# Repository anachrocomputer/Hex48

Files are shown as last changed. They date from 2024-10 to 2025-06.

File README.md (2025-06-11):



# Hex48 #

PCB design for a hexagonal prototyping board capable of holding DIL chips with
up to 48 pins.

## The Problem ##

Everybody has prototyping PCBs in rectangular form, but what other shapes tesselate well?
How about hexagons, would they work?
And why stop at 40-pin DIL packages when chips like the 68008 come in 48-pin DIL?

## The Solution ##

This PCB design mounts the DIL part on a hexagonal board that can be easily tesselated.
It has mounting holes for M3 PCB standoffs, or it can be fitted with non-slip feet.
In extreme cases, a heavy base can be made out of an insulator such as slate.

## KiCad ##

This design has been created using the Open Source CAD package KiCad, V8.0.

To install it on Ubuntu Linux:

`sudo add-apt-repository ppa:kicad/kicad-8.0-releases`

`sudo apt update`

`sudo apt install kicad`

I'm using Ubuntu 22.04 LTS which would give me the very outdated KiCad V6.0 by default.
As I write this, the latest KiCad is V8.0.5,
which is a big upgrade from the V6.0 which I started with.

## PCB Photo ##
Photo of the PCB, as manufactured.

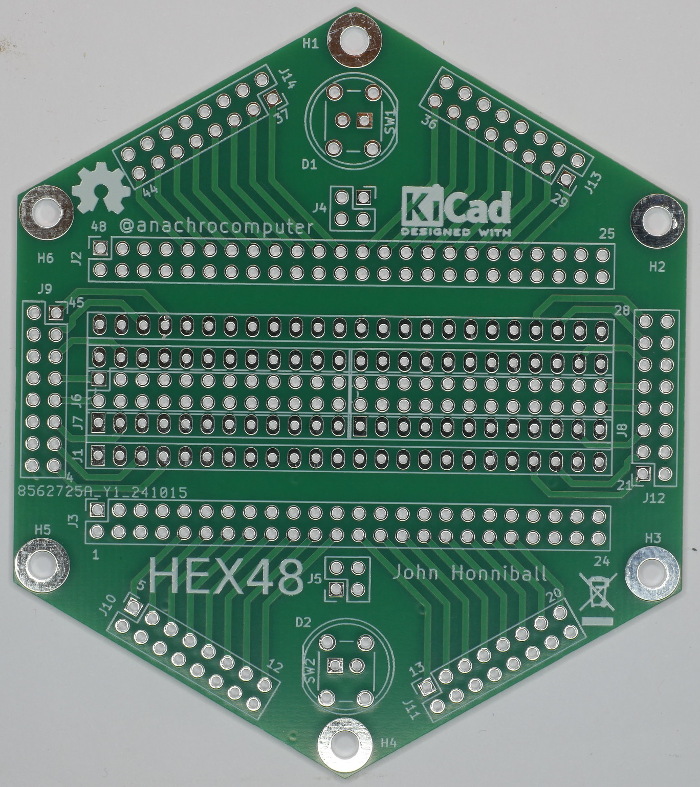
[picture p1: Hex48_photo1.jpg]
PCB photo


PCB with sockets and headers soldered on, mounted on a base made out of slate.

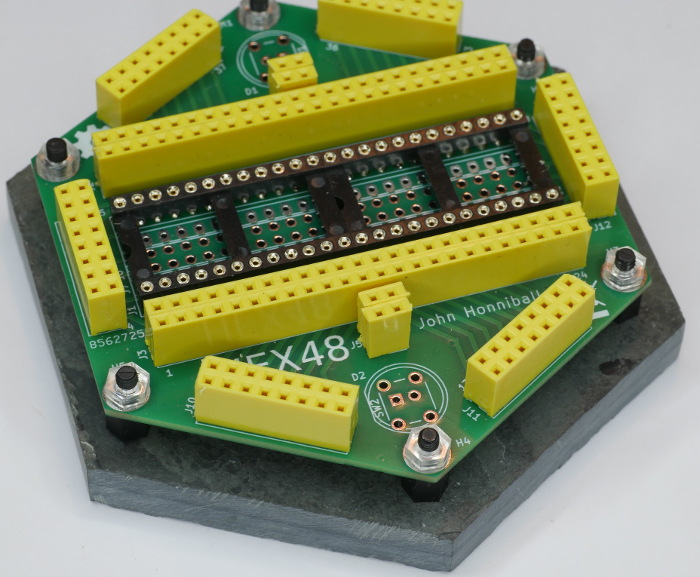
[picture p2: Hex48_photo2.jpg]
Populated PCB photo


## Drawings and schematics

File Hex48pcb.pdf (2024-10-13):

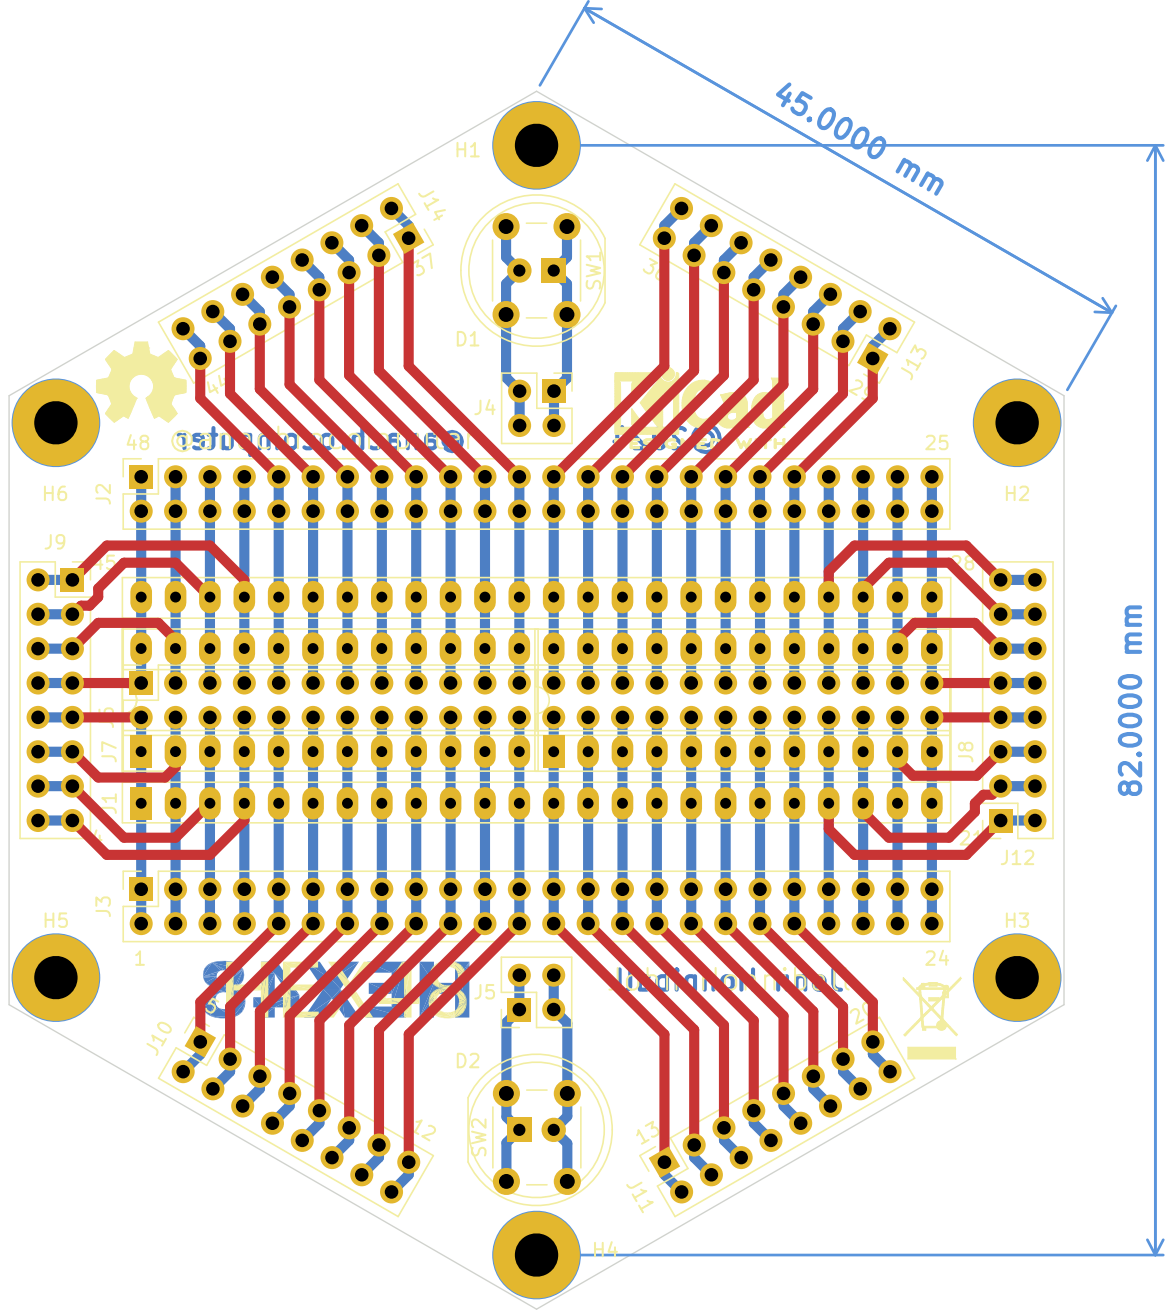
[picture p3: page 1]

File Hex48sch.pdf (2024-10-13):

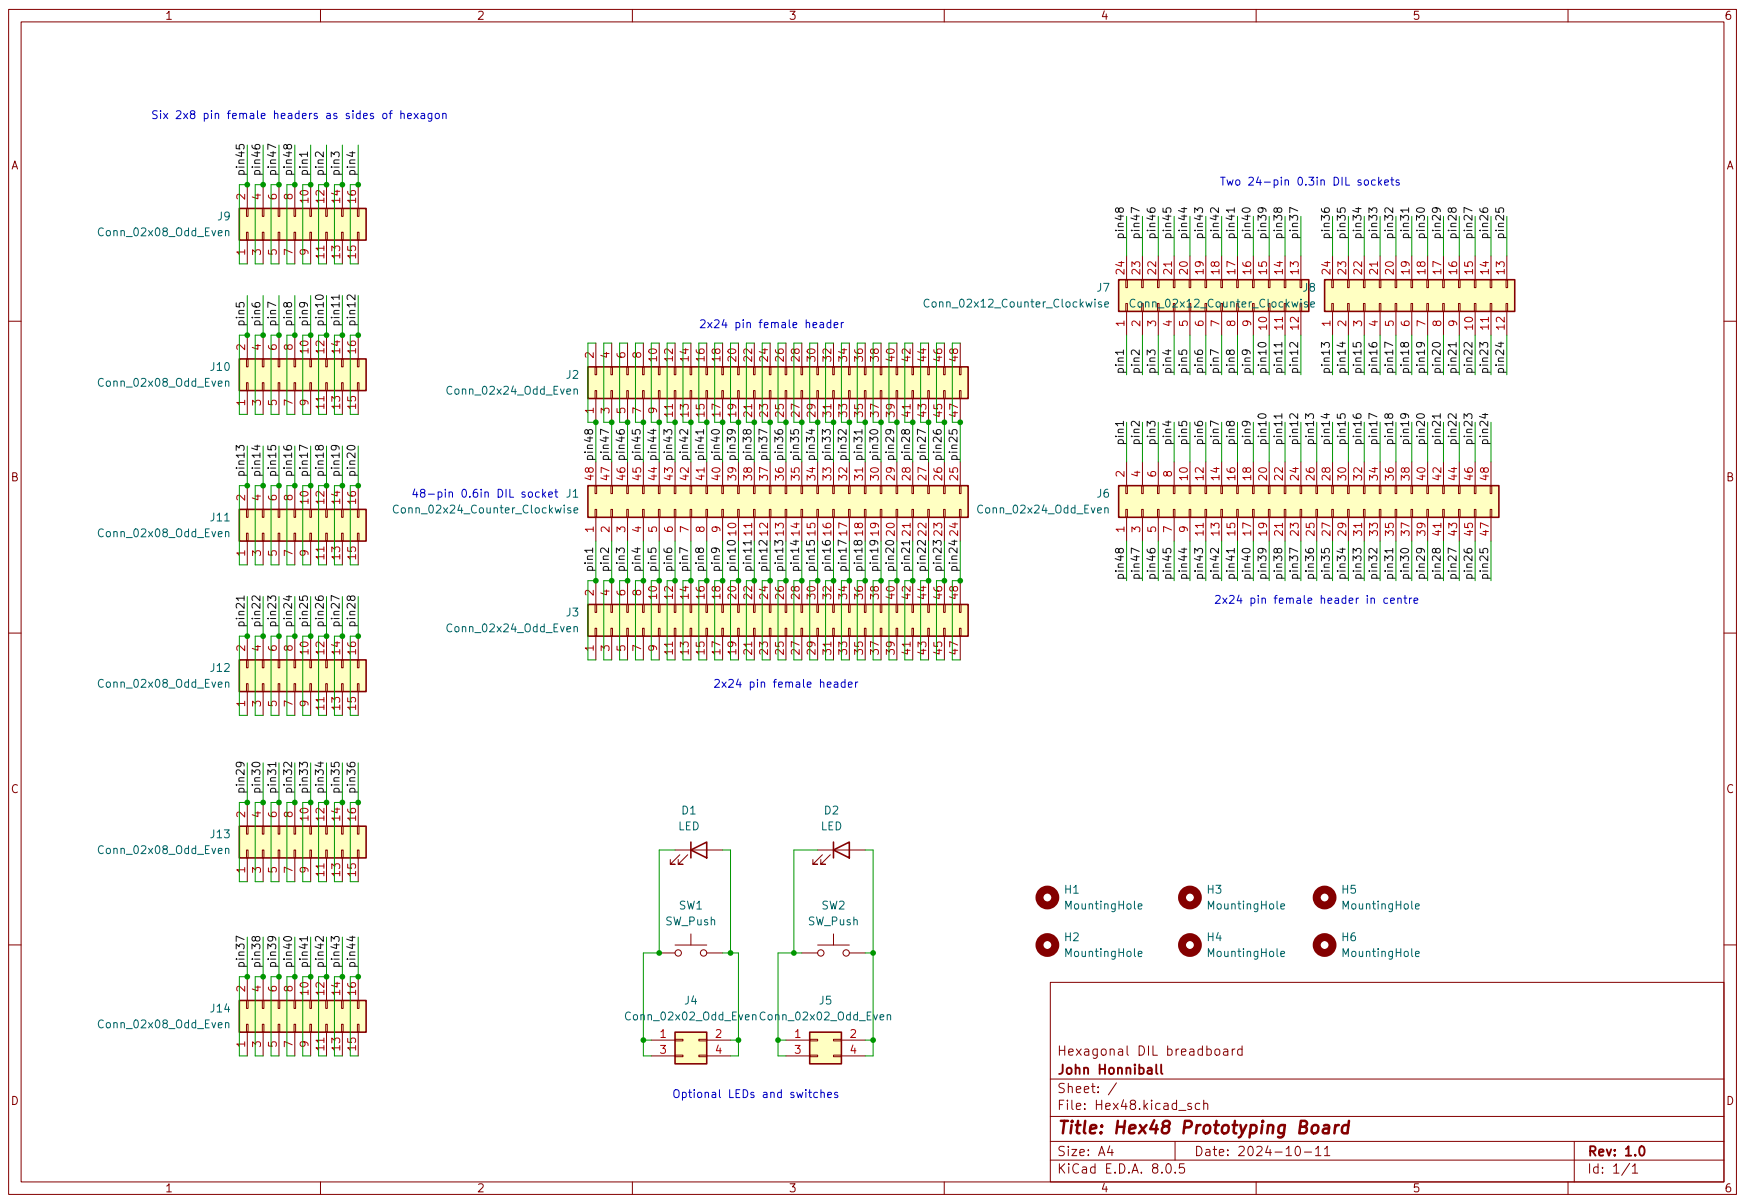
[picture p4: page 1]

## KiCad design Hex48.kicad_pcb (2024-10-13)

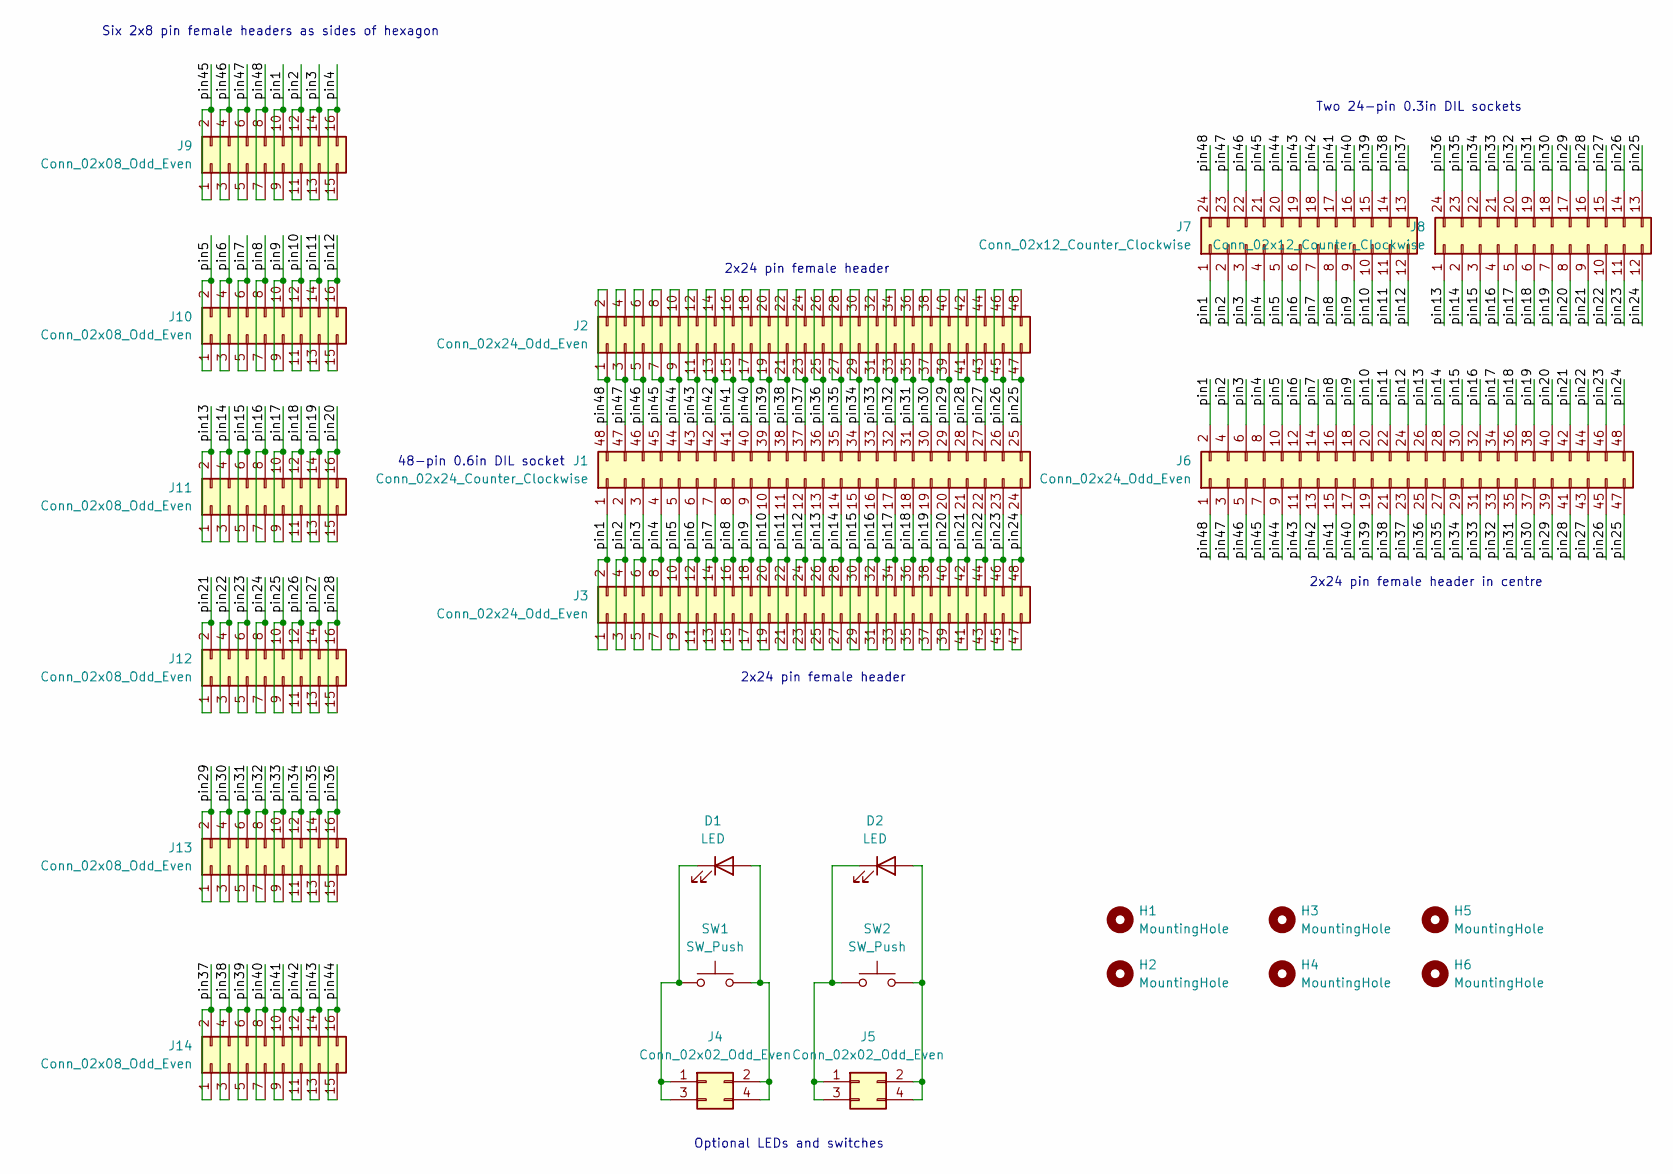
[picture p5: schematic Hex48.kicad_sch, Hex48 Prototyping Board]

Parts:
D1, D2: LED; LED_D10.0mm
H1, H2, H3, H4, H5, H6: MountingHole; MountingHole_3.2mm_M3_Pad
J1: Conn_02x24_Counter_Clockwise; DIP-48_W15.24mm_Socket_LongPads
J2, J3, J6: Conn_02x24_Odd_Even; PinSocket_2x24_P2.54mm_Vertical
J4, J5: Conn_02x02_Odd_Even; PinSocket_2x02_P2.54mm_Vertical
J7, J8: Conn_02x12_Counter_Clockwise; DIP-24_W7.62mm_Socket_LongPads
J9, J10, J11, J12, J13, J14: Conn_02x08_Odd_Even; PinSocket_2x08_P2.54mm_Vertical
SW1, SW2: SW_Push; SW_PUSH_6mm

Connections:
/pin1: J1.1, J3.1, J3.2, J6.2, J7.1, J9.9, J9.10
/pin2: J1.2, J3.3, J3.4, J6.4, J7.2, J9.11, J9.12
/pin3: J1.3, J3.5, J3.6, J6.6, J7.3, J9.13, J9.14
/pin4: J1.4, J3.7, J3.8, J6.8, J7.4, J9.15, J9.16
/pin5: J1.5, J3.9, J3.10, J6.10, J7.5, J10.1, J10.2
/pin6: J1.6, J3.11, J3.12, J6.12, J7.6, J10.3, J10.4
/pin7: J1.7, J3.13, J3.14, J6.14, J7.7, J10.5, J10.6
/pin8: J1.8, J3.15, J3.16, J6.16, J7.8, J10.7, J10.8
/pin9: J1.9, J3.17, J3.18, J6.18, J7.9, J10.9, J10.10
/pin10: J1.10, J3.19, J3.20, J6.20, J7.10, J10.11, J10.12
/pin11: J1.11, J3.21, J3.22, J6.22, J7.11, J10.13, J10.14
/pin12: J1.12, J3.23, J3.24, J6.24, J7.12, J10.15, J10.16
/pin13: J1.13, J3.25, J3.26, J6.26, J8.1, J11.1, J11.2
/pin14: J1.14, J3.27, J3.28, J6.28, J8.2, J11.3, J11.4
/pin15: J1.15, J3.29, J3.30, J6.30, J8.3, J11.5, J11.6
/pin16: J1.16, J3.31, J3.32, J6.32, J8.4, J11.7, J11.8
/pin17: J1.17, J3.33, J3.34, J6.34, J8.5, J11.9, J11.10
/pin18: J1.18, J3.35, J3.36, J6.36, J8.6, J11.11, J11.12
/pin19: J1.19, J3.37, J3.38, J6.38, J8.7, J11.13, J11.14
/pin20: J1.20, J3.39, J3.40, J6.40, J8.8, J11.15, J11.16
/pin21: J1.21, J3.41, J3.42, J6.42, J8.9, J12.1, J12.2
/pin22: J1.22, J3.43, J3.44, J6.44, J8.10, J12.3, J12.4
/pin23: J1.23, J3.45, J3.46, J6.46, J8.11, J12.5, J12.6
/pin24: J1.24, J3.47, J3.48, J6.48, J8.12, J12.7, J12.8
/pin25: J1.25, J2.47, J2.48, J6.47, J8.13, J12.9, J12.10
/pin26: J1.26, J2.45, J2.46, J6.45, J8.14, J12.11, J12.12
/pin27: J1.27, J2.43, J2.44, J6.43, J8.15, J12.13, J12.14
/pin28: J1.28, J2.41, J2.42, J6.41, J8.16, J12.15, J12.16
/pin29: J1.29, J2.39, J2.40, J6.39, J8.17, J13.1, J13.2
/pin30: J1.30, J2.37, J2.38, J6.37, J8.18, J13.3, J13.4
/pin31: J1.31, J2.35, J2.36, J6.35, J8.19, J13.5, J13.6
/pin32: J1.32, J2.33, J2.34, J6.33, J8.20, J13.7, J13.8
/pin33: J1.33, J2.31, J2.32, J6.31, J8.21, J13.9, J13.10
/pin34: J1.34, J2.29, J2.30, J6.29, J8.22, J13.11, J13.12
/pin35: J1.35, J2.27, J2.28, J6.27, J8.23, J13.13, J13.14
/pin36: J1.36, J2.25, J2.26, J6.25, J8.24, J13.15, J13.16
/pin37: J1.37, J2.23, J2.24, J6.23, J7.13, J14.1, J14.2
/pin38: J1.38, J2.21, J2.22, J6.21, J7.14, J14.3, J14.4
/pin39: J1.39, J2.19, J2.20, J6.19, J7.15, J14.5, J14.6
/pin40: J1.40, J2.17, J2.18, J6.17, J7.16, J14.7, J14.8
/pin41: J1.41, J2.15, J2.16, J6.15, J7.17, J14.9, J14.10
/pin42: J1.42, J2.13, J2.14, J6.13, J7.18, J14.11, J14.12
/pin43: J1.43, J2.11, J2.12, J6.11, J7.19, J14.13, J14.14
/pin44: J1.44, J2.9, J2.10, J6.9, J7.20, J14.15, J14.16
/pin45: J1.45, J2.7, J2.8, J6.7, J7.21, J9.1, J9.2
/pin46: J1.46, J2.5, J2.6, J6.5, J7.22, J9.3, J9.4
/pin47: J1.47, J2.3, J2.4, J6.3, J7.23, J9.5, J9.6
/pin48: J1.48, J2.1, J2.2, J6.1, J7.24, J9.7, J9.8
unnamed: D1.2 (A), J4.2, J4.4, SW1.2
unnamed: D1.1 (K), J4.1, J4.3, SW1.1
unnamed: D2.2 (A), J5.2, J5.4, SW2.2
unnamed: D2.1 (K), J5.1, J5.3, SW2.1

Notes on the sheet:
2x24 pin female header
Six 2x8 pin female headers as sides of hexagon
Optional LEDs and switches
Two 24-pin 0.3in DIL sockets
2x24 pin female header in centre
48-pin 0.6in DIL socket

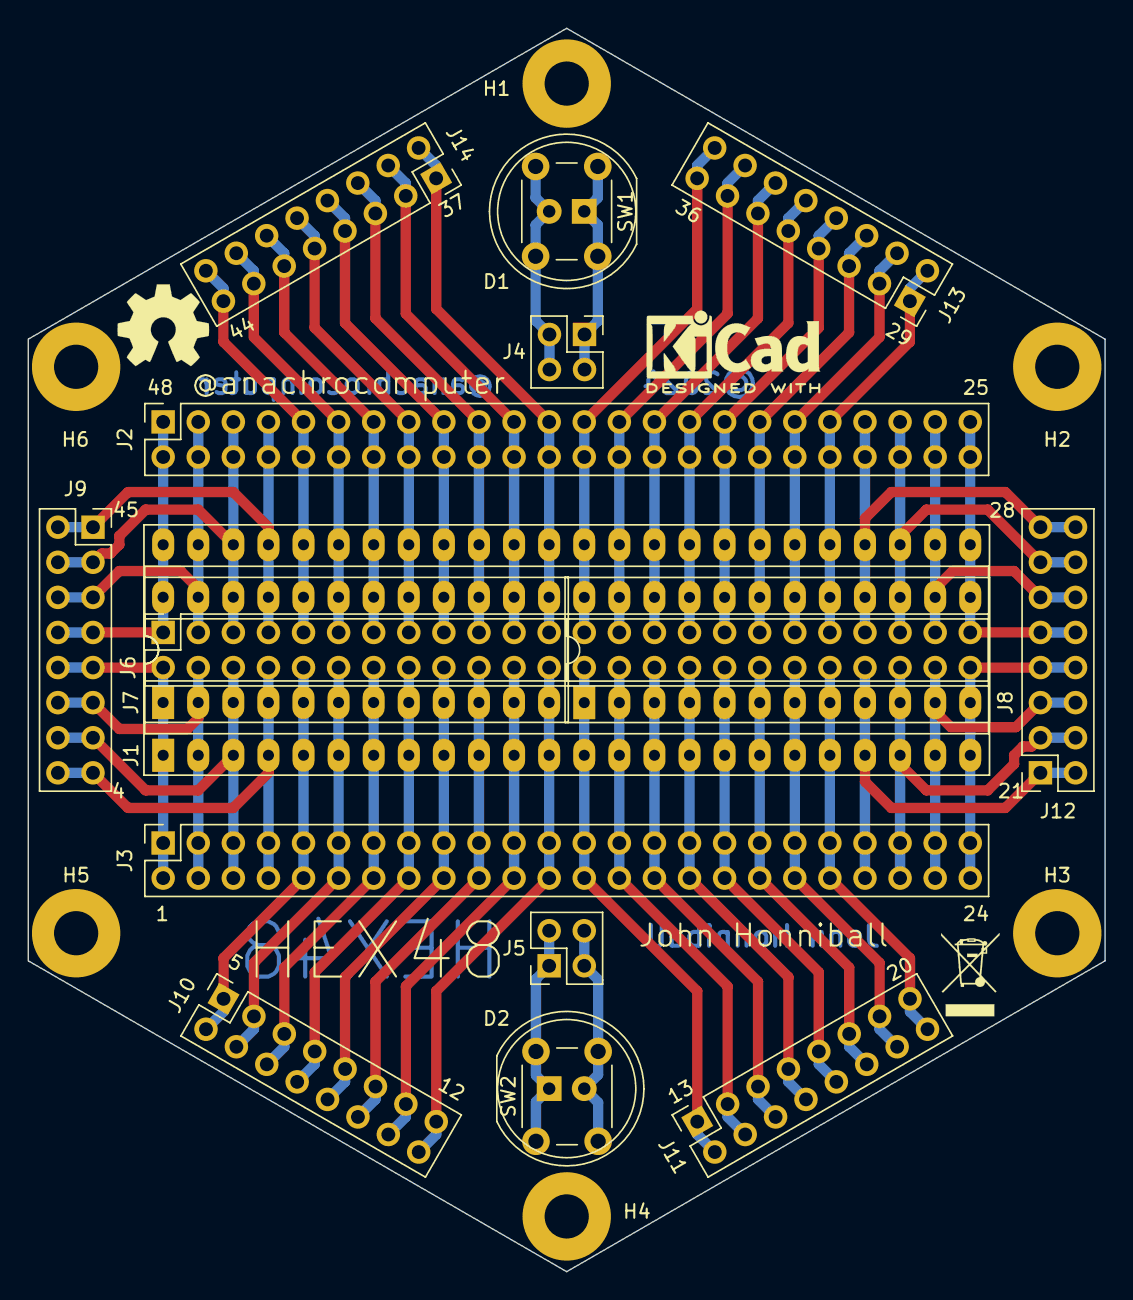
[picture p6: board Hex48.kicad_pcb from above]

Board: 2 copper layers, 77.9 x 90.0 mm, 24 parts (0 on the bottom side), 52 nets.

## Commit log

2023-08-28 Initial commit.
    Really early version, mostly just to see if the parts fit. No Schematic yet, but does a PCB like this even need a schematic?
    [Hex48.kicad_pcb, Hex48.kicad_sch]
2024-09-27 Big upgrade to KiCad V8.0.
    Automatic upgrade seemed to go OK.
    [Hex48.kicad_pcb, Hex48.kicad_sch]
2024-10-09 Begin adding schematic.
    Board is much better designed by using a proper schematic instead of just a PCB. But to do that, we need lots of generic connectors, all connected together in a way that only makes sense on the physi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
    [Hex48.kicad_pcb, Hex48.kicad_sch]
2024-10-09 Add title block info.
    [Hex48.kicad_sch]
2024-10-10 Finish DIL wiring.
    Place two 24-pin narrow DIL sockets and connect them to the 48-pin wide DIL socket. Name all pin signals.
    [Hex48.kicad_pcb, Hex48.kicad_sch]
2024-10-10 Fix heinous typo.
    Also add designer's name and update datestamp.
    [Hex48.kicad_pcb]
2024-10-10 Finish schematic, map all footprints,update PCB.
    Rats-nest now complete. Some parts placed on PCB in final locations. Some parts (mounting holes and 2x8 headers) need to be placed exactly on a polar grid at 60-degree intervals.
    [Hex48.kicad_pcb, Hex48.kicad_sch]
2024-10-11 Final schematic, V1.0.
    Add some text comments.
    [Hex48.kicad_sch]
2024-10-11 Place footprints on PCB in exact locations.
    PCB edges, mounting holes, connectors, and LEDs/switches in correct places. Footprints locked to avoid mistakes. Initial rear copper tracks added. Dimensions of hexagon and mounting holes added. TODO: lots more tack routing.
    [Hex48.kicad_pcb]
2024-10-12 Route all tracks.
    Try to put tracks on top where they will be visible and self-documenting. Tracks at 45 degrees under 60-degree mounted headers look a bit odd, but they work. All tracks 0.75mm wide. Some spacings a bit tight, may move.
    [Hex48.kicad_pcb]
2024-10-13 Move eight tracks just a little bit further from the sockets.
    [Hex48.kicad_pcb]
2024-10-13 Add pin numbers to silkscreen.
    Just a few, because the true pin number will change if you fit a 40-pin chip, or two 24-pin chips, or three 16-pin chips. Better to follow the tracks visually.
    [Hex48.kicad_pcb]
2024-10-13 Add silkscreen and back copper text.
    KiCad logo, OSHW logo, WEEE logo, name, designers name, date. That Twitter handle is going to look very old very quickly.
    [Hex48.kicad_pcb]
2024-10-13 V1.0: ready to go to fab.
    Also add PDFs of schematic and PCB.
    [Hex48.kicad_pcb]
2024-11-20 Add photo of finished board.
    Remove dire warning.
2024-11-20 Add photo of populated PCB.

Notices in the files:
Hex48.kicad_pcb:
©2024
